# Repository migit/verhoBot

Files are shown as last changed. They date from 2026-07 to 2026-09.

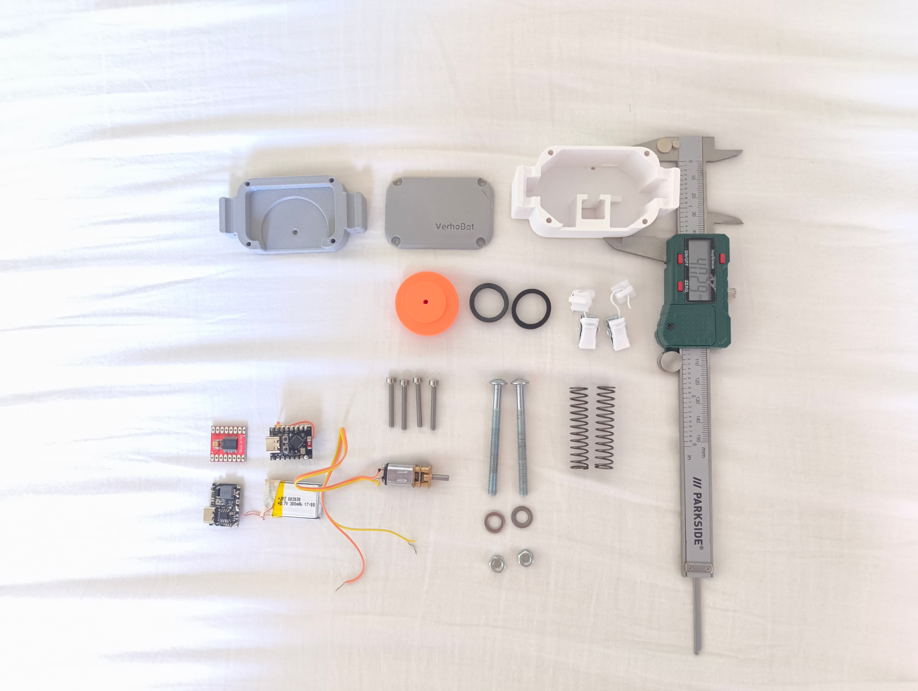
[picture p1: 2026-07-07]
VerhoBot/hardware/CAD/images/VerhoBot_parts.jpg

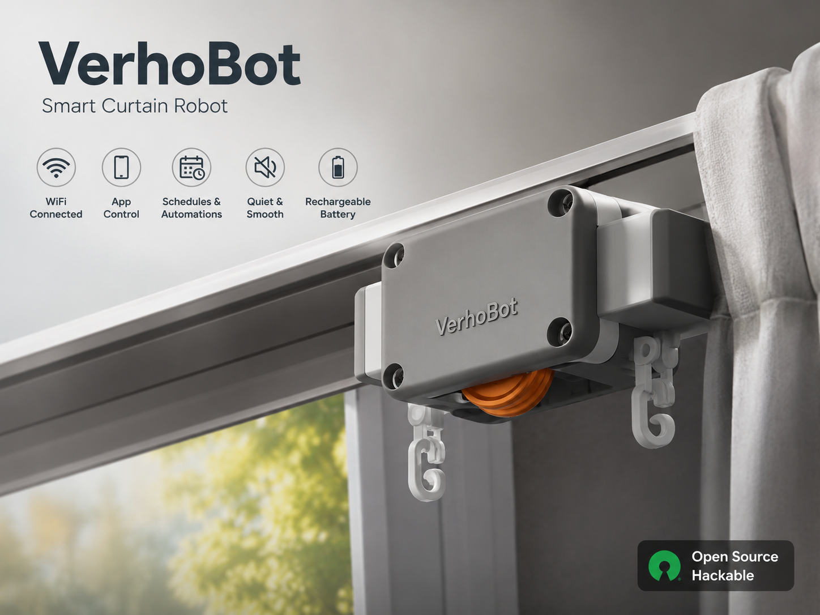
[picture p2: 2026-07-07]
VerhoBot/hardware/CAD/images/vb.png

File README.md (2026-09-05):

<!-- # VerhoBot
<img width="1536" height="1024" alt="verho_concept_design" src="https://github.com/user-attachments/assets/45290109-c627-40e5-b835-4a0c27403841" /> 
<img width="1536" height="1024" alt="verho_b" src="https://github.com/user-attachments/assets/ea8144e8-805f-48bb-890e-384471ef9897" /> -->

<!-- <img width="1535" height="1024" alt="verho_banner" src="https://github.com/user-attachments/assets/6782ed62-eeb0-4958-a5c3-7888029129f1" /> 

<img width="1535" height="1024" alt="verho_banner_white" src="https://github.com/user-attachments/assets/3a6c4d62-edfc-40f7-b2f0-12bc582d1462" /> -->

<picture>
  <source media="(prefers-color-scheme: dark)" srcset="https://github.com/user-attachments/assets/aba6153e-b872-4d4a-9a58-02b24fb0d8ed">
  <source media="(prefers-color-scheme: light)" srcset="https://github.com/user-attachments/assets/56020f1e-bfad-4f00-b733-0ede581f7c40">
  verho_banner
</picture>

<div align="center">

### The Tiny Bot That Opens and Closes Your Curtains for You

*Sleep in darkness. Wake up with sunlight.*

[]()
[]()
[]()
[]()


[]()


</div>

---

## Overview

VerhoBot is an open-source smart curtain robot designed to automate existing curtain rails using affordable, widely available hardware and fully customizable software.

The project was born from a simple observation: many people use blackout curtains to improve sleep quality, but those same curtains prevent natural sunlight from entering the room when it is time to wake up. This challenge is particularly noticeable during the Finnish summer, when long daylight hours and bright nights can disrupt normal sleep patterns.

VerhoBot addresses this problem by providing a compact robotic platform capable of opening and closing curtains automatically according to schedules, user commands, or future smart-home automations.

Unlike many commercial curtain robots, VerhoBot is designed from the beginning as an open-source project. Every aspect of the system including hardware design, firmware, mechanical components, and future software integrations is intended to be accessible, modifiable, and extensible by makers, students, engineers, and hobbyists.

**VerhoBot** solves both problems.

VerhoBot is a compact curtain-moving robot designed to automatically close your curtains when you need darkness and open them again when it is time to wake up. The goal is simple: improve sleep quality while letting natural sunlight become part of your morning routine.

Built around the ESP32 platform, VerhoBot aims to be affordable, repairable, open-source, and easy to integrate into modern smart homes.

---

## Features

### Current Goals

- Automatic curtain opening and closing
- Compact rail-mounted design
- Battery-powered operation
- ESP32-based controller
- Quiet operation
- USB-C charging
- Low-power sleep modes
- Open-source hardware and software

### Planned Features

- Scheduled curtain control 
- Sunrise and sunset automation
- Home Assistant integration
- Mobile configuration
- OTA firmware updates
- Battery monitoring
- Manual override controls
- Position calibration
- Smart alarm mode

---

## Why?

Finland's summer is famous for its bright nights.

While blackout curtains help create a dark sleeping environment, they also block the morning sunlight that helps regulate the body's natural wake-up cycle.

VerhoBot combines the best of both worlds:

- Darkness when you need sleep
- Sunlight when it is time to wake up

No alarms.
No bright phone screens.
Just natural light at the right moment.
The long-term vision of VerhoBot is to create a flexible, affordable, and fully open curtain automation platform that can evolve through community contributions.
Rather than competing with commercial smarthome products, VerhoBot aims to give users complete ownership of their hardware, software, and data while remaining accessible to makers of all skill levels.

## Comunity Goals

The project aims to provide a practical open-source platform for learning:

Embedded systems
ESP32 development
Mechanical design
Battery-powered electronics
IoT communication
Smart-home integration
Product development

Whether you are building your first ESP32 project or developing advanced automation systems, VerhoBot should provide a foundation that is easy to understand, modify, and improve.

---

## Hardware

###  Electronics

| Component | Purpose |
|---|---|
| ESP32-C3 supermini | Main controller |
| N20 Geared DC Motor (100 RPM 6V works best without loosing good torque and speed) | Curtain movement |
| Motor Driver (TB6612FNG is chosen for best effeciency and size form factor) | Motor control |
| Li-Ion Battery (3.7v 300mAh is chosen) | Portable power |
| USB-C Charger | Charging interface |
| Position Sensors (note yet decide, but position calibration is now done in the firmware for now : const uint32_t CURTAIN_TRAVEL_TIME = 4000;)| Open/close detection |

### schematic

<picture>
  <source media="(prefers-color-scheme: dark)" srcset="https://github.com/user-attachments/assets/5fd002bf-6933-44c8-951e-679d403ac9f6">
  <source media="(prefers-color-scheme: light)" srcset="https://github.com/user-attachments/assets/78fb31f9-d5d8-4c3f-95c0-13649d746854">
  verho_banner
</picture>

### PCB design
-PCB design is active now, I will release the first draft, so that the community can comment on it before it is has been manufactured (Help is wanted here)

###  Mechanical Design

vbot1

- Compact form factor
- Rail-mounted operation
- Existing curtain compatibility
- 3D-printable enclosure built arround the designed PCB board
- Modular internal architecture

<div align="center">
  <a href="https://www.youtube.com/watch?v=YXQe8-dixHU">
    Watch the video
  </a>
</div>

<div align="center">
  <a href="https://youtu.be/6-GEg8fdRDQ?si=6PpPOxxIadroxERF">
    Watch the video
  </a>
</div>

### Parts

VerhoBot_parts

[Join the thingsverse community here](https://www.thingiverse.com/thing:7370927)

---

## Software Roadmap

### Phase 1

- Basic motor control [Done]
- Position calibration [Done]
- Manual open/close control [Done]

### Phase 2

- Scheduling system [Done]
- Battery monitoring [Done]
- Configuration interface [Done] 

### Phase 3

- OTA updates [Done]
- Web-based firmware flasher (Done,)
- Home Assistant integration [Pending...for Version 2]
- Smart automation features [Pending... for Version 2]

### NOTE: All software, firware and hardware works of this project is complete and in stable version but verho bot is still evolving as V2 as next generation VerhoBot, meanning This repo (V1) will continue to be mainatined and evolve without affecting the OSHWA certification standard and what it promised to deliver. 

---

## operation

<!-- <img width="1264" height="833" alt="op_mode" src="https://github.com/user-attachments/assets/f6f8d905-06a9-4c95-84db-494406e7b41f" /> -->
VerhoBot - visual selection

## How it suppose to behave:
- First boot -> AP VerhoBot-Setup -> dashboard at 192.168.4.1 -> click ⚙ to enter WiFi & schedule -> save -> reboot.
- Normal operation -> connects to home WiFi -> syncs time -> sleeps.
- Scheduled wake -> moves curtain -> starts web server -> stays awake 60 s -> sleeps.
- Button wake -> toggles curtain -> starts web server -> stays awake 60 s -> sleeps.
- During the 60‑second awake window, you can open your browser, go to the device’s IP (shown in Serial), and see the full dashboard, control the curtain, and check telemetry.
- After 60 s of inactivity, it goes back to deep sleep.

## Quick Troubleshooting:

- It restarts automatically after saving, and should join your home WiFi. The VerhoBot-Setup network will disappear (expected - that's the sign it's now trying your real WiFi).
- Find it on your network. It'll get an IP from your router. Easiest way: check your router's connected-devices list for "verhobot" or similar, or use a phone WiFi scanner app / your router admin page. There's no verhobot.local mDNS support yet, so this is the one manual step for now.
- Open the dashboard at that IP. You should see the schedule card showing your configured open/close times and a live countdown to the next action.
If it doesn't show up on your network within a minute or two, it likely couldn't connect (wrong password, wrong network, etc.) - with the fix from earlier, it'll fall back to broadcasting VerhoBot-Setup again so you can fix the credentials. Reconnect to that and try /setup again.
- Calibrate the position once it's mounted on the actual curtain rail - run it fully open and fully closed once, then use the "set as fully open / fully closed" buttons on the dashboard so the tracked position matches reality (it's timing-based, not sensor-based, so it can drift).
- Mount it and let it run unattended - check back around your first scheduled open/close time to confirm it moves as expected, then it should just run on its own, waking briefly at each scheduled event and sleeping the rest of the time.

- If it connects fine and everything looks right, you're basically done - just keep an eye on battery level on the dashboard for the first few days to get a sense of how long it lasts between charges.

## Project Status

```text

v_0.1.0-beta1.2  -> Firmware complete
v_0.1.0-beta1.1  -> Testing and tuning
v_0.1.0-beta1  ->   Manual open/close control
v1.0  -> Stable release
v1.1  -> Stable with Improved dashboard
V1.2  -> OTA feature added
V1.2.1 -> Fixed a boot button deep sleep wake to GPIO1 as esp32-c3 does not support this
```

Active patching is ongoing but stable phase.

## Lesson Learned 

- So far verhoBot is being tested for over two weeks, firmware bug is being fixed so plugging and unplugging the USB C was a headache, so impliment OTA at the early stage saved me time.
- Control & config dashboard is being improved scheduling,OTA update, home wifi connect and curtain calibration (time based) are working flowlessly these are small features so working on them separately was a good idea even if they seem small and manageable.
- On the hardware side wakr up GPIO has been added. Before, it was suppose to work with boot button press which the esp32-c super mini board does not support
- The deep sleep has saved lots of battery life but the LED (I call it the terminator eye) glows in the dark was cool indicating the bot is on but still consumes battery life, in the future desoldering it from the board will defenetly save some more battery life.
- The Li-Po battery I am using is 300mAh, still the bot runs for 6 days straight...(I will update this when I finish experimenting on it!).I leaned battery size (physical size) matters and as the battery gets bigger the form factor of the bot case changes I should have considered this before I designed the case but hey, now harm!

--- 

## Design Principles

VerhoBot follows a few simple rules:

- Open-source first
- Repairable hardware
- Affordable components
- Low power consumption
- Easy to build
- Easy to modify
- No vendor lock-in (you own everything)

---

## Future versions may incorporate:

- Position sensing
- Motor current monitoring
- Automatic obstacle detection
- Endstop detection
- Environmental sensors
- Advanced power management

---

## Demo

#Dashboard preview:

https://github.com/user-attachments/assets/f727beac-c3cd-45c5-90aa-1bad3a5c13f2

## Contributing

Contributions, ideas, testing feedback, and hardware improvements are welcome.
As the project evolves, documentation, CAD files, schematics, and firmware source code will be published in this repository.

---

## License

Distributed under the MIT License.
See `LICENSE` for more information.

VerhoBot has been officially certified as Open Source Hardware by the Open Source Hardware Association (OSHWA).

- **Certification UID:** FI000004
- **Certification Date:** 2026
- **Status:** OSHWA Certified Open Source Hardware

This project complies with the Open Source Hardware Definition and all design files are publicly available.
For more information about Open Source Hardware certification, visit the Open Source Hardware Association (OSHWA).

[OSHWA Certified Open Source Hardware FI000004](https://certification.oshwa.org/fi000004.html)

---

<div align="center">

### VerhoBot

*Built for the Finnish summer. Makers for Makers*

</div>

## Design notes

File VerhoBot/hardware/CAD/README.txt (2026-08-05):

# VerhoBot

**Designed by MikeMakesStuffs on Thingiverse**
**Thingiverse:** https://www.thingiverse.com/thing:7370927

---

# Summary

**VerhoBot** is an open-source smart curtain robot designed to automate existing curtain rails using affordable, widely available hardware.

Built around the **ESP32-C3 Super Mini** and an **N20 geared motor**, VerhoBot is easy to build, easy to modify, and completely open source. Whether you need a simple curtain timer or a fully featured smart-home device, VerhoBot provides a flexible platform for makers, engineers, and DIY enthusiasts.

---

# Why VerhoBot?

Many people use blackout curtains to improve sleep quality, but waking up naturally with sunlight is just as important.

VerhoBot automatically opens or closes your curtains:

- On a schedule
- Through a web interface
- Via future smart-home integrations

The project was inspired by Finnish summers, where bright nights and early morning sunlight can make maintaining a healthy sleep schedule difficult.

---

# Features

- ESP32-C3 Super Mini based
- Battery powered (LiPo)
- USB-C charging
- N20 geared motor
- TB6612FNG motor driver
- Built-in Wi-Fi web control dashboard
- Configure and calibrate directly from the browser
- Fully 3D printable enclosure *(stable release with only minor refinements remaining)*
- Open-source firmware
- Modular hardware design
- Designed specifically for curtain rails
- Lightweight and compact

---

# Firmware

The firmware is continuously updated.

Latest releases are available here:

**Firmware Flasher:**

https://myworks.gt.tc/verhobot/

---

# Hardware

## Current Version (V1)

- ESP32-C3 Super Mini
- N20 DC Geared Motor
  - Recommended: **100 RPM 6V**
  - Good balance between speed and torque
- TB6612FNG Motor Driver
- TP4056 Charging Module
- 3.7V LiPo Battery
  - Recommended capacity: **300 mAh**
- MT3608 Boost Converter *(optional if the TP4056 includes a built-in boost converter)*
- Custom 3D printed enclosure and mechanical components

---

# Open Source

VerhoBot is intended to be a community-driven project.

Future community extensions may include:

- Home Assistant integration
- MQTT support
- Matter compatibility
- Zigbee connectivity
- Position tracking
- Automatic calibration
- Obstacle detection
- Battery optimization
- Solar charging
- Mobile applications

Contributions, remixes, improvements, and pull requests are always welcome.

---

# Source Code & Documentation

## GitHub Repository

https://github.com/migit/verhoBot

The repository contains:

- Firmware
- Firmware Flasher
- Electronics documentation
- Schematics
- 3D models
- Build instructions
- Future development roadmap

Firmware is also hosted here:

https://myworks.gt.tc/verhobot/

---

# Philosophy

> **Build it. Improve it. Share it.**

VerhoBot is more than a curtain robot.

It is an open platform for learning:

- Embedded systems
- Mechanical design
- Battery-powered electronics
- Smart-home automation

If you build one, remix it, improve it, or adapt it for your own project, please share your version with the community.

---

# Current Project Status

## Firmware is now in a stable version!

### announcement 

Development on the hardware side has slowed down for the summer.
The current **VerhoBot V1.0** hardware is fully functional, while software development will continue to expand its capabilities.

Now it's your turn:
 
- Hack it
- Improve it
- Customize it
- Make it even better
---

# Thank You

Thank you all so much for your support!

---

# Videos

## Full Build Video

https://www.youtube.com/watch?v=6-GEg8fdRDQ

## Tinkering Demo

https://www.youtube.com/watch?v=YXQe8-dixHU

---

# Sleep in darkness. Wake up with sunlight.

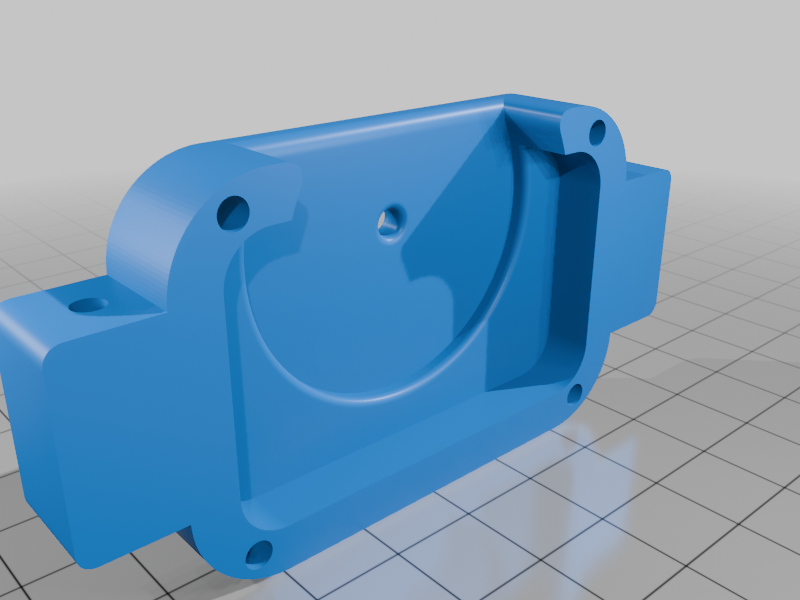
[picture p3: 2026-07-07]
VerhoBot/hardware/CAD/images/VerhoBot_-_front.png

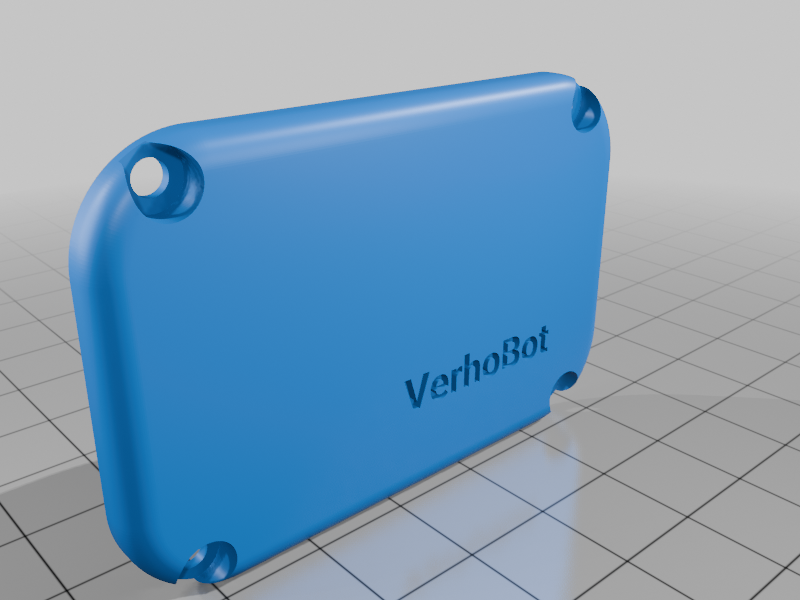
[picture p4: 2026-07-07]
VerhoBot/hardware/CAD/images/cover_face_-_Part_1.png

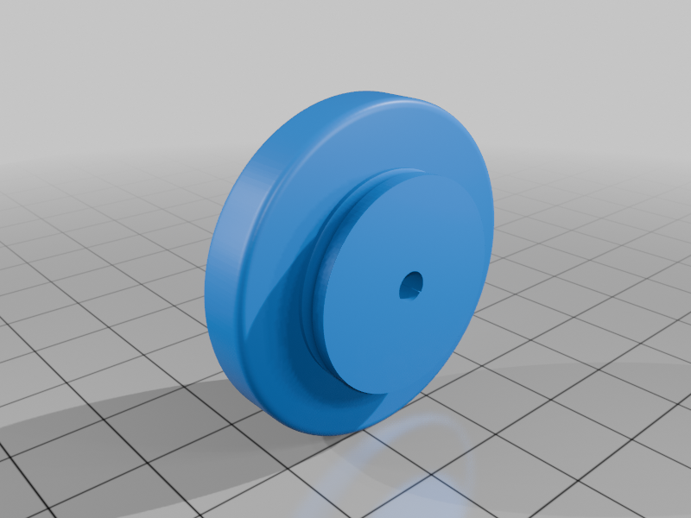
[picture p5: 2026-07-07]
VerhoBot/hardware/CAD/images/VerhoBot_-_Part_1_1.png

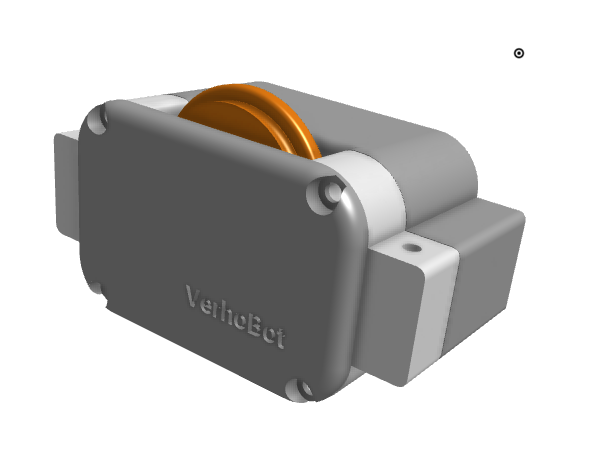
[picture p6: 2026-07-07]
VerhoBot/hardware/CAD/images/verho.png

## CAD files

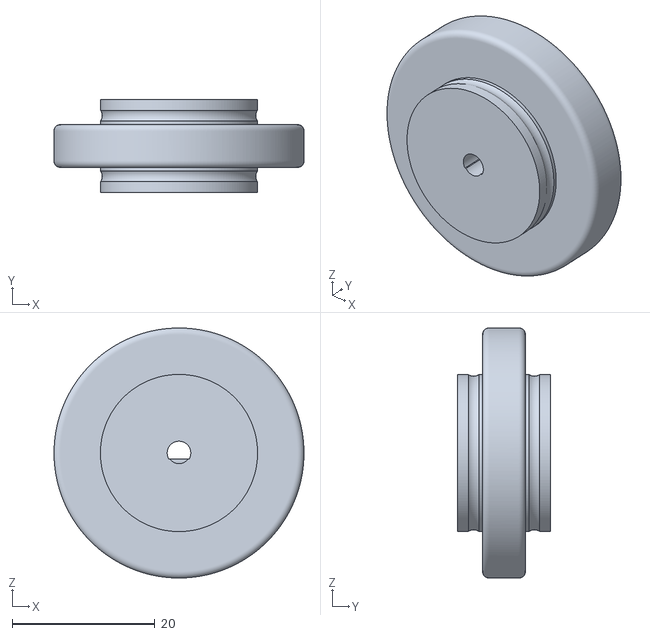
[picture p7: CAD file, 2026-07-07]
VerhoBot/hardware/CAD/files/VerhoBot_-_Part_1_1.stl
35.0 x 13.0 x 35.0

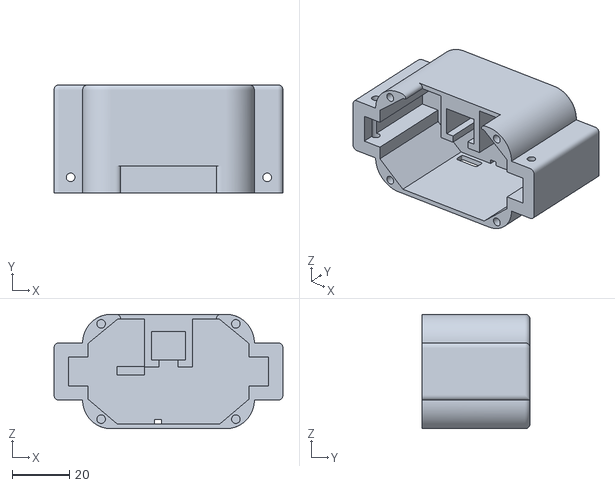
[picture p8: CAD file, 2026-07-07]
VerhoBot/hardware/CAD/files/VerhoBot_-_back.stl
80.0 x 37.8 x 40.0

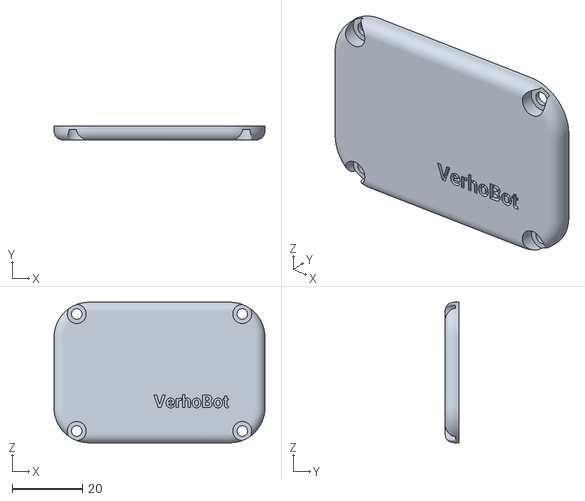
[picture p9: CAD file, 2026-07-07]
VerhoBot/hardware/CAD/files/cover_face_-_Part_1.stl
60.0 x 4.00 x 40.0

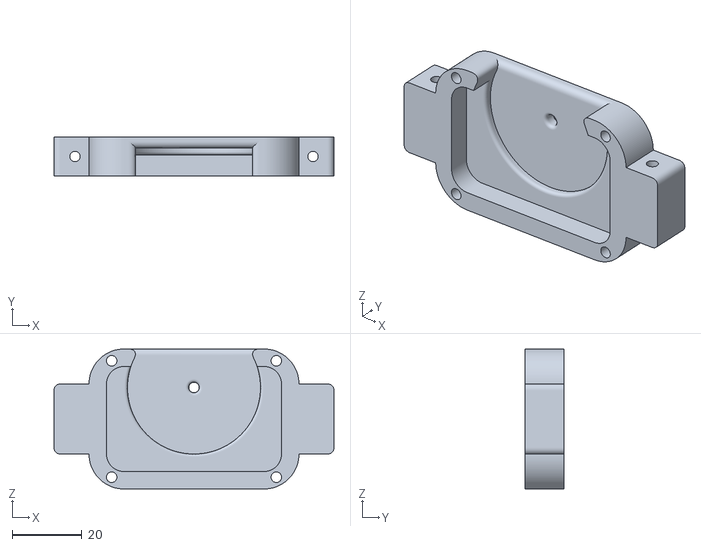
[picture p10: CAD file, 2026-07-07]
VerhoBot/hardware/CAD/files/VerhoBot_-_front.stl
80.0 x 11.0 x 40.0

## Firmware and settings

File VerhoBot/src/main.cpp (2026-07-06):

#include <Arduino.h>
#include <WiFi.h>
#include <WebServer.h>
#include <Preferences.h>
#include <time.h>
#include <esp_sleep.h>
#include <ArduinoJson.h>
#include <Update.h>

#include "pins.h"

// ============================================================
//  RTC memory – survives deep sleep
// ============================================================
RTC_DATA_ATTR float rtcCurtainPos = 0.0f;
RTC_DATA_ATTR uint32_t rtcBootCount = 0;

// ============================================================
//  Preferences (non‑volatile storage)
// ============================================================
Preferences prefs;

// ============================================================
//  Global state
// ============================================================
enum CurtainState { IDLE, OPENING, CLOSING };
CurtainState state = IDLE;

uint32_t moveStart    = 0;
uint32_t moveDuration = 0;
float    curtainPos   = 0.0f;   // 0.0 = fully open, 1.0 = fully closed

// Configuration loaded from Preferences
String wifiSSID = "";
String wifiPass = "";
int    openHour = 7;
int    openMin  = 0;
int    closeHour = 22;
int    closeMin  = 0;
String tzString  = TIMEZONE_STRING;
String otaToken  = ""; // empty = OTA disabled until set in /setup
bool   configured = false;
bool   otaInProgress = false; // guards against deep-sleeping mid-flash-write
bool   otaAuthFailed = false; // set when the passcode check fails; checked before reboot

// Web server
WebServer server(80);

// Awake timeout (STA mode only)
uint32_t awakeStart = 0;
const uint32_t AWAKE_TIMEOUT = 60000;  // 60 seconds after motor stops

// ============================================================
//  Motor control (non‑blocking, PWM soft start / soft stop)
// ============================================================
// PWMA is driven via LEDC instead of digitalWrite so we can ramp the duty
// cycle. Direction pins (AIN1/AIN2) stay as plain digital outputs.

void motorSetDuty(uint8_t duty) {
#if ESP_ARDUINO_VERSION_MAJOR >= 3
    ledcWrite(PWMA, duty);           // core 3.x: pin-addressed LEDC
#else
    ledcWrite(PWM_CHANNEL, duty);    // core <3.0: channel-addressed LEDC
#endif
}

void motorOpen() {
    digitalWrite(AIN1, HIGH);
    digitalWrite(AIN2, LOW);
    motorSetDuty(0); // ramp handled by updateMotor()
}

void motorClose() {
    digitalWrite(AIN1, LOW);
    digitalWrite(AIN2, HIGH);
    motorSetDuty(0); // ramp handled by updateMotor()
}

void motorStop() {
    digitalWrite(AIN1, LOW);
    digitalWrite(AIN2, LOW);
    motorSetDuty(0);
}

void startOpen(uint32_t ms) {
    if (curtainPos <= 0.01f) return;
    motorOpen();
    state = OPENING;
    moveStart = millis();
    moveDuration = ms;
    awakeStart = millis(); // keep awake while moving
}

void startClose(uint32_t ms) {
    if (curtainPos >= 0.99f) return;
    motorClose();
    state = CLOSING;
    moveStart = millis();
    moveDuration = ms;
    awakeStart = millis(); // keep awake while moving
}

void stopMotor() {
    if (state != IDLE) {
        float fraction = (float)(millis() - moveStart) / (float)moveDuration;
        fraction = constrain(fraction, 0.0f, 1.0f);
        if (state == OPENING) curtainPos = max(curtainPos - fraction, 0.0f);
        if (state == CLOSING) curtainPos = min(curtainPos + fraction, 1.0f);
    }
    motorStop();
    state = IDLE;
    awakeStart = millis(); // start the 60‑second countdown
}

// Linearly ramps duty from `from` to `to` over [0, rampMs] given `elapsed`.
static uint8_t rampDuty(uint32_t elapsed, uint32_t rampMs, uint8_t from, uint8_t to) {
    if (rampMs == 0 || elapsed >= rampMs) return to;
    float t = (float)elapsed / (float)rampMs;
    return (uint8_t)(from + t * ((float)to - (float)from));
}

void updateMotor() {
    if (state == IDLE) return;

    uint32_t elapsed = millis() - moveStart;

    if (elapsed >= moveDuration || elapsed >= MAX_RUN_TIME) {
        stopMotor();
        return;
    }

    uint32_t remaining = moveDuration - elapsed;

    uint8_t duty;
    if (elapsed < MOTOR_RAMP_UP_MS) {
        // Soft start: 0 -> full speed
        duty = rampDuty(elapsed, MOTOR_RAMP_UP_MS, 0, PWM_MAX_DUTY);
    } else if (remaining < MOTOR_RAMP_DOWN_MS) {
        // Soft stop: full speed -> min duty (stopMotor() cuts the rest cleanly)
        uint32_t decelElapsed = MOTOR_RAMP_DOWN_MS - remaining;
        duty = rampDuty(decelElapsed, MOTOR_RAMP_DOWN_MS, PWM_MAX_DUTY, MOTOR_MIN_DUTY);
    } else {
        duty = PWM_MAX_DUTY;
    }

    motorSetDuty(duty);
}

// Drive toward an absolute position (0.0 = fully open, 1.0 = fully closed),
// scaling the move duration to the remaining distance so the dashboard's
// drag-to-set slider lands close to where the user dropped it.
void gotoPosition(float targetPos) {
    targetPos = constrain(targetPos, 0.0f, 1.0f);
    float diff = targetPos - curtainPos;
    if (fabs(diff) < 0.01f) return; // already there
    uint32_t ms = (uint32_t)(fabs(diff) * CURTAIN_TRAVEL_TIME);
    if (ms < 80) return; // too small a move to bother with
    if (diff > 0) startClose(ms);
    else          startOpen(ms);
}

// ============================================================
//  Battery monitoring
// ============================================================
float readBatteryVoltage() {
    uint32_t sum = 0;
    for (uint8_t i = 0; i < ADC_SAMPLES; i++) sum += analogRead(BATTERY_ADC);
    float adcVoltage = ((float)(sum / ADC_SAMPLES) / 4095.0f) * 3.3f;
    return adcVoltage * BATTERY_CAL;
}

// ============================================================
//  Preferences (save / load / clear)
// ============================================================
void saveConfig(String ssid, String pass, int oh, int om, int ch, int cm, String tz, String ota) {
    prefs.begin("verhobot", false);
    prefs.putString("ssid", ssid);
    prefs.putString("pass", pass);
    prefs.putInt("openH", oh);
    prefs.putInt("openM", om);
    prefs.putInt("closeH", ch);
    prefs.putInt("closeM", cm);
    prefs.putString("tz", tz);
    prefs.putString("ota", ota);
    prefs.putBool("configured", true);
    prefs.end();
}

void loadConfig() {
    prefs.begin("verhobot", true);
    wifiSSID   = prefs.getString("ssid", "");
    wifiPass   = prefs.getString("pass", "");
    openHour   = prefs.getInt("openH", 7);
    openMin    = prefs.getInt("openM", 0);
    closeHour  = prefs.getInt("closeH", 22);
    closeMin   = prefs.getInt("closeM", 0);
    tzString   = prefs.getString("tz", TIMEZONE_STRING);
    otaToken   = prefs.getString("ota", "");
    configured = prefs.getBool("configured", false);
    prefs.end();
}

void clearConfig() {
    prefs.begin("verhobot", false);
    prefs.clear();
    prefs.end();
    configured = false;
}

// ============================================================
//  Time / NTP sync (with timeout)
// ============================================================
bool syncTime() {
    if (WiFi.status() != WL_CONNECTED) return false;
    // Use a POSIX TZ string (configurable, see /setup) instead of raw UTC
    // offsets so DST is handled automatically. Previously this called
    // configTime(0, 0, ...), which left the RTC in UTC and made scheduled
    // open/close times silently off by 2-3 hours in Finland.
    configTzTime(tzString.c_str(), "pool.ntp.org", "time.google.com");
    time_t now = time(nullptr);
    int attempts = 0;
    while (now < 8 * 3600 * 2 && attempts < 30) {
        delay(250);
        now = time(nullptr);
        attempts++;
    }
    return (now > 8 * 3600);
}

String getTimeString() {
    time_t now = time(nullptr);
    struct tm *info = localtime(&now);
    char buf[30];
    strftime(buf, sizeof(buf), "%Y-%m-%d %H:%M:%S", info);
    return String(buf);
}

// ============================================================
//  Deep sleep preparation
// ============================================================
struct NextEvent {
    bool     isOpenEvent; // true = the pending action is OPEN, false = CLOSE
    int      hour;
    int      minute;
    uint64_t secondsUntil;
};

NextEvent computeNextEvent() {
    NextEvent ev;
    time_t now = time(nullptr);
    struct tm *tm_now = localtime(&now);

    // BUGFIX: this used to pick the SAME edge the curtain just reached
    // (closed -> target closeHour again), which meant a device that fell
    // asleep closed would sleep straight through the next openHour and
    // only ever wake up at closeHour, 24h later. It must target the
    // *opposite* edge - the one that hasn't happened yet.
    if (curtainPos > 0.5f) {
        // currently closed -> next thing to do is OPEN
        ev.isOpenEvent = true;
        ev.hour = openHour;
        ev.minute = openMin;
    } else {
        // currently open -> next thing to do is CLOSE
        ev.isOpenEvent = false;
        ev.hour = closeHour;
        ev.minute = closeMin;
    }

    struct tm target = *tm_now;
    target.tm_hour = ev.hour;
    target.tm_min  = ev.minute;
    target.tm_sec  = 0;

    time_t targetTime = mktime(&target);
    if (targetTime <= now) targetTime += 86400;

    ev.secondsUntil = (uint64_t)(targetTime - now);
    return ev;
}

uint64_t calculateSleepSeconds() {
    return computeNextEvent().secondsUntil;
}

bool inFallbackAP = false; // true only when AP is up because STA failed post-config (see below)

void enterDeepSleep() {
    Serial.println("Entering deep sleep...");
    delay(100);

    rtcCurtainPos = curtainPos;

    motorStop();
    digitalWrite(STBY, LOW);

    WiFi.disconnect(true);
    WiFi.mode(WIFI_OFF);

    bool timeSynced = (time(nullptr) > 8 * 3600);
    uint64_t sleepSec;
    if (timeSynced) {
        sleepSec = computeNextEvent().secondsUntil;
    } else {
        // Clock isn't trustworthy (WiFi/NTP failed this cycle) - computing a
        // schedule-based sleep duration from an unsynced clock (effectively
        // Jan 1 1970) could sleep for a wildly wrong number of hours. Retry
        // again shortly instead of trusting it.
        sleepSec = UNSYNCED_RETRY_SEC;
        Serial.println("Clock not synced - using a short fixed retry interval instead of the schedule.");
    }

    esp_sleep_enable_timer_wakeup(sleepSec * 1000000ULL);

    // The ESP32-C3 is RISC-V and has no dedicated RTC GPIO mux, so it
    // doesn't support ext0/ext1 wakeup sources the way the original ESP32,
    // S2, and S3 do. It uses a separate GPIO wakeup API instead.
#if CONFIG_IDF_TARGET_ESP32 || CONFIG_IDF_TARGET_ESP32S2 || CONFIG_IDF_TARGET_ESP32S3
    esp_sleep_enable_ext1_wakeup(1ULL << WAKE_BUTTON_PIN, ESP_EXT1_WAKEUP_ANY_LOW);
#else
    esp_deep_sleep_enable_gpio_wakeup(1ULL << WAKE_BUTTON_PIN, ESP_GPIO_WAKEUP_GPIO_LOW);
#endif

    if (timeSynced) {
        Serial.printf("Sleeping for %llu seconds (schedule-based)\n", sleepSec);
    } else {
        Serial.printf("Sleeping for %llu seconds (retry, clock unsynced)\n", sleepSec);
    }
    Serial.flush();

    esp_deep_sleep_start();
}

// ============================================================
//  Web Server – Full Dashboard + Setup
// ============================================================

// ---------- DASHBOARD PAGE (with ghost animation) ----------
const char PAGE_DASHBOARD[] PROGMEM = R"rawhtml(
<!DOCTYPE html>
<html lang="en">
<head>
<meta charset="UTF-8">
<meta name="viewport" content="width=device-width, initial-scale=1">
<title>VerhoBot</title>
<style>
:root{
  --bg:#f5f4f0;--surface:#faf9f6;
  --ink:#1a1a1a;--ink2:#3a3a3a;
  --mute:#8a8a85;--rule:#c8c7c0;--rule2:#dddcd6;
  --green:#1a6b3a;--red:#8b1a1a;--amber:#8a5a00;
  --mono:'Courier New',Courier,'Lucida Console',monospace;
  --sans:-apple-system,BlinkMacSystemFont,'Segoe UI',Helvetica,Arial,sans-serif;
  /* Accent + sky follow the curtain state: warm dawn when open (daylight
     coming in), cool dusk when closed (night). Set by JS via body attrs. */
  --accent:#c2560c;--accent-dim:rgba(194,86,12,0.10);--accent-border:rgba(194,86,12,0.35);
  --sky-a:#f3e2c8;--sky-b:#f5f4f0;
}
body[data-phase="night"]{
  --accent:#38477a;--accent-dim:rgba(56,71,122,0.12);--accent-border:rgba(56,71,122,0.4);
  --sky-a:#20264a;--sky-b:#3a4472;
}
*,*::before,*::after{box-sizing:border-box;margin:0;padding:0;}
body{
  background:var(--bg);color:var(--ink);font-family:var(--sans);
  min-height:100vh;padding:1.5rem 1rem 3rem;
  background-image:
    linear-gradient(var(--rule2) 1px,transparent 1px),
    linear-gradient(90deg,var(--rule2) 1px,transparent 1px);
  background-size:24px 24px;
  transition:background .6s ease;
}
.wrap{max-width:480px;margin:0 auto;}

header{
  display:flex;justify-content:space-between;align-items:flex-start;
  border-bottom:2px solid var(--ink);padding-bottom:10px;margin-bottom:1rem;
  position:relative;
}
header::after{
  content:'';position:absolute;bottom:-2px;left:0;width:48px;height:2px;
  background:var(--accent);transition:background .6s ease;
}
.logo{
  font-family:var(--mono);font-size:1.5rem;letter-spacing:.1em;
  display:flex;align-items:baseline;gap:0;line-height:1;
}
.logo-verho{color:var(--ink);font-weight:normal;}
.logo-slash{color:var(--accent);margin:0 1px;transition:color .6s ease;}
.logo-bot{color:var(--accent);font-weight:bold;letter-spacing:.06em;transition:color .6s ease;}
.logo-sub{font-family:var(--mono);font-size:.5rem;letter-spacing:.2em;color:var(--mute);margin-top:5px;text-transform:uppercase;}
.hdr-right{text-align:right;}
.conn{font-family:var(--mono);font-size:.52rem;letter-spacing:.15em;text-transform:uppercase;
  display:flex;align-items:center;gap:5px;color:var(--green);justify-content:flex-end;}
.conn-dot{width:6px;height:6px;border-radius:50%;background:var(--green);animation:blink 2.5s steps(1) infinite;}
#conn-offline{color:var(--red);display:none;}
#conn-offline .conn-dot{background:var(--red);animation:none;}
@keyframes blink{0%,100%{opacity:1}50%{opacity:0}}
.mode-badge{font-family:var(--mono);font-size:.44rem;letter-spacing:.12em;color:var(--mute);margin-top:3px;text-transform:uppercase;}
.ip{font-family:var(--mono);font-size:.46rem;letter-spacing:.1em;color:var(--mute);margin-top:2px;}
.gear{display:inline-block;font-size:1.1rem;cursor:pointer;text-decoration:none;color:var(--mute);transition:transform 0.3s;margin-top:4px;}
.gear:hover{transform:rotate(60deg);color:var(--accent);}

.banner{
  font-family:var(--mono);font-size:.56rem;letter-spacing:.05em;
  padding:8px 10px;border:1px solid var(--amber);color:var(--amber);
  background:rgba(138,90,0,.06);margin-bottom:1rem;display:none;
  align-items:center;gap:8px;
}
.banner.show{display:flex;}
.banner.danger{border-color:var(--red);color:var(--red);background:rgba(139,26,26,.06);}
.banner-dot{width:6px;height:6px;flex:0 0 auto;border-radius:50%;background:currentColor;}

.section{
  font-family:var(--mono);font-size:.52rem;letter-spacing:.2em;text-transform:uppercase;
  color:var(--accent);margin-bottom:8px;display:flex;align-items:center;gap:8px;
  transition:color .6s ease;
}
.section::after{content:'';flex:1;height:1px;background:var(--rule);}

.curtain-block{border:1px solid var(--ink2);margin-bottom:1.25rem;}
.curtain-head{
  background:var(--ink);color:#f5f4f0;
  font-family:var(--mono);font-size:.58rem;letter-spacing:.18em;
  padding:5px 10px;display:flex;justify-content:space-between;
}
.curtain-head span:last-child{color:var(--accent);transition:color .6s ease;}
.curtain-vis{
  position:relative;height:96px;overflow:hidden;cursor:grab;
  background:linear-gradient(180deg,var(--sky-a),var(--sky-b));
  transition:background 1s ease;
  touch-action:none;
}
.curtain-vis:active{cursor:grabbing;}
.curtain-vis::before{content:'';position:absolute;top:0;left:0;right:0;height:3px;background:var(--ink);z-index:4;}
.drape{
  position:absolute;top:3px;left:0;height:calc(100% - 3px);
  background:var(--accent-dim);
  border-right:1.5px solid var(--accent-border);
  overflow:hidden;z-index:1;
  transition:background .6s ease,border-color .6s ease;
}
.drape::after{
  content:'';position:absolute;inset:0;
  background-image:repeating-linear-gradient(45deg,transparent,transparent 4px,rgba(0,0,0,.05) 4px,rgba(0,0,0,.05) 5px);
}
.drape-ghost{
  position:absolute;top:3px;left:0;height:calc(100% - 3px);
  background:transparent;border-right:2px dashed var(--accent-border);
  pointer-events:none;z-index:2;display:none;
}
.ring{position:absolute;top:-2px;width:7px;height:7px;border:1.5px solid var(--ink);border-radius:50%;background:var(--bg);transform:translateX(-50%);z-index:3;pointer-events:none;}
.handle{
  position:absolute;top:50%;width:16px;height:16px;border-radius:50%;
  background:#fff;border:2px solid var(--ink);transform:translate(-50%,-50%);
  z-index:5;box-shadow:0 1px 3px rgba(0,0,0,.3);
}
.curtain-foot{border-top:1px solid var(--rule);padding:6px 10px;display:flex;justify-content:space-between;align-items:center;}
.pos-scale{font-family:var(--mono);font-size:.46rem;letter-spacing:.05em;color:var(--mute);}
.pos-right{display:flex;align-items:center;gap:10px;}
.state-badge{
  font-family:var(--mono);font-size:.48rem;letter-spacing:.15em;text-transform:uppercase;
  padding:2px 7px;border:1px solid var(--ink2);color:var(--ink2);
}
.state-badge.opening,.state-badge.closing{border-color:var(--accent);color:var(--accent);}
.pos-pct{font-family:var(--mono);font-size:1rem;font-weight:700;color:var(--accent);transition:color .6s ease;}

.metrics{display:grid;grid-template-columns:1fr 1fr 1fr;border:1px solid var(--ink2);margin-bottom:1.25rem;}
.metric{padding:.75rem .9rem;border-right:1px solid var(--rule);}
.metric:last-child{border-right:none;}
.m-label{font-family:var(--mono);font-size:.46rem;letter-spacing:.18em;text-transform:uppercase;color:var(--mute);margin-bottom:5px;}
.m-val{font-family:var(--mono);font-size:.92rem;font-weight:700;line-height:1;}
.m-unit{font-family:var(--mono);font-size:.48rem;color:var(--mute);margin-left:1px;}
.bbar-row{margin-top:5px;display:flex;align-items:center;gap:5px;}
.bbar-track{flex:1;height:3px;background:var(--rule2);}
.bbar-fill{height:100%;background:var(--ink);transition:width .6s ease,background .3s ease;}

.sched-block{border:1px solid var(--ink2);margin-bottom:1.25rem;padding:.8rem .9rem;}
.sched-row{display:flex;justify-content:space-between;align-items:baseline;}
.sched-label{font-family:var(--mono);font-size:.46rem;letter-spacing:.16em;text-transform:uppercase;color:var(--mute);}
.sched-times{font-family:var(--mono);font-size:.6rem;color:var(--ink2);margin-top:4px;}
.sched-next{font-family:var(--mono);font-size:.78rem;font-weight:700;color:var(--accent);margin-top:2px;transition:color .6s ease;}
.sched-note{font-family:var(--mono);font-size:.46rem;color:var(--mute);margin-top:6px;}

.controls{display:grid;grid-template-columns:1fr 1fr 1fr;border:1px solid var(--ink2);margin-bottom:.6rem;}
.cmd{
  all:unset;cursor:pointer;
  font-family:var(--mono);font-size:.58rem;letter-spacing:.15em;text-transform:uppercase;
  text-align:center;color:var(--ink2);
  padding:.85rem .4rem;
  display:flex;flex-direction:column;align-items:center;gap:7px;
  border-right:1px solid var(--rule);
  transition:background .12s,color .12s,border-color .12s,opacity .2s;
  position:relative;
}
.cmd:last-child{border-right:none;}
.cmd:active{transform:scale(.98);}
.cmd[aria-disabled="true"]{opacity:.35;pointer-events:none;}
.cmd svg{width:22px;height:22px;stroke:var(--ink2);fill:none;stroke-width:1.5;stroke-linecap:round;stroke-linejoin:round;transition:stroke .12s;}
.cmd.open:hover,.cmd.close:hover{background:var(--accent);color:#fff;}
.cmd.open:hover svg,.cmd.close:hover svg{stroke:#fff;}
.cmd.stop:hover{background:var(--ink);color:#f5f4f0;}
.cmd.stop:hover svg{stroke:#f5f4f0;}

.calib-row{display:flex;justify-content:center;gap:1.5rem;margin-bottom:1.25rem;}
.calib-btn{
  all:unset;cursor:pointer;font-family:var(--mono);font-size:.46rem;letter-spacing:.1em;
  text-transform:uppercase;color:var(--mute);border-bottom:1px dotted var(--mute);
  padding-bottom:1px;
}
.calib-btn:hover{color:var(--accent);border-color:var(--accent);}

.log-block{border:1px solid var(--rule);margin-bottom:1.25rem;}
.log-head{font-family:var(--mono);font-size:.52rem;letter-spacing:.18em;text-transform:uppercase;color:var(--mute);padding:5px 10px;border-bottom:1px solid var(--rule);display:flex;justify-content:space-between;}
#log{padding:8px 10px;font-family:var(--mono);font-size:.58rem;color:var(--mute);line-height:2;min-height:80px;max-height:180px;overflow-y:auto;}
.lt{color:var(--rule);margin-right:8px;}
.ok{color:var(--green);}
.er{color:var(--red);}
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
void loop() {
    server.handleClient();
    updateMotor();

    // ---- AP mode: stay awake ----
    if (WiFi.getMode() == WIFI_AP) {
        // The never-configured setup AP (CASE 1) stays up indefinitely -
        // that's an out-of-box, actively-being-set-up state.
        // The fallback AP (saved credentials failed to connect) is bounded:
        // if nobody connects to fix it within AP_FALLBACK_TIMEOUT_MS, give
        // up and go back to sleep to retry the saved network later, rather
        // than burning battery broadcasting an AP with nobody around.
        if (inFallbackAP && millis() - awakeStart > AP_FALLBACK_TIMEOUT_MS) {
            Serial.println("No one connected to the fallback AP in time - sleeping to retry the saved network later.");
            enterDeepSleep();
        }
        return;
    }

    // ---- STA mode: sleep after 60s of idle ----
    if (otaInProgress) {
        // A firmware upload can easily take longer than AWAKE_TIMEOUT on a
        // slow network - never let it get cut off by a deep sleep mid-write.
        awakeStart = millis();
    } else if (state == IDLE) {
        if (millis() - awakeStart > AWAKE_TIMEOUT) {
            enterDeepSleep();
        }
    } else {
        // motor is moving – keep resetting the awake timer
        awakeStart = millis();
    }
}

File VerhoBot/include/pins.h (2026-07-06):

#ifndef PINS_H
#define PINS_H

// ---- Motor Driver (TB6612FNG) ----
#define AIN1    2
#define AIN2    3
#define PWMA    4
#define STBY    5

// ---- Battery Voltage Divider ----
#define BATTERY_ADC 0

// ---- Wake Button ----
// The ESP32-C3's onboard BOOT button is on GPIO9 - but the C3 only supports
// waking from DEEP sleep on GPIO0-5 (GPIO9 can wake from light sleep or
// trigger a normal reset, but not this). So the wake button can not be the
// module's built-in BOOT button; it has to be a separate button wired to
// one of GPIO0-5. GPIO1 is the only one of those not already used by the
// motor driver or battery sense, so that is what this needs to be wired to.
#define WAKE_BUTTON_PIN 1

// ---- Motor timing ----
#define CURTAIN_TRAVEL_TIME 4000   // ms for full travel (will be auto‑calibrated later)
#define MAX_RUN_TIME         8000  // safety cutoff
#define BATTERY_CAL          2.08f // voltage divider factor
#define ADC_SAMPLES          16

// ---- Motor PWM (soft start / soft stop) ----
#define PWM_FREQ              20000  // 20kHz, above audible range
#define PWM_RESOLUTION_BITS   8      // duty range 0-255
#define PWM_MAX_DUTY          ((1 << PWM_RESOLUTION_BITS) - 1)
#define PWM_CHANNEL           0      // only used on arduino-esp32 core < 3.0
#define MOTOR_RAMP_UP_MS      300    // time to reach full speed from stop
#define MOTOR_RAMP_DOWN_MS    300    // time to decelerate before a scheduled stop
#define MOTOR_MIN_DUTY        60     // duty floor while ramping (below this the motor may stall, not spin)

// ---- Timezone (POSIX TZ string) ----
// Default: Europe/Helsinki (EET/EEST with automatic DST).
// Change this if you build VerhoBot outside Finland.
// Reference table: https://github.com/nayarsystems/posix_tz_db
#define TIMEZONE_STRING "EET-2EEST,M3.5.0/3,M10.5.0/4"

// ---- WiFi connection / recovery timing ----
#define WIFI_CONNECT_TIMEOUT_MS   15000              // how long to try joining the saved network
#define AP_FALLBACK_TIMEOUT_MS    (5UL*60UL*1000UL)  // give up on fallback AP + go back to sleep after this
#define UNSYNCED_RETRY_SEC        (15UL*60UL)        // retry interval when NTP sync fails (clock can't be trusted for scheduling)

#endif

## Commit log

2026-06-16 Update ESP32 to ESP32-C3 in README
2026-06-22 Increase curtain travel time from 1000 to 4000 ms
    The bot travel time is increased for testing and calibration
2026-06-27 Add pins.h for motor driver and sensor definitions
    added wake up button use boot button (pin 0 for now)
2026-06-27 Update pins.h
    wake up button added, use BOOT button on ESP32‑C3 SuperMini, GPIO9 for now
2026-06-27 Update main.cpp
    patch missing dashboard html code
    [main.cpp]
2026-06-27 Document device operation and scheduled behavior
    Added operational behavior details for the device.
2026-07-02 Refactor motor control and time sync handling
    Refactor motor control to use PWM for soft start/stop and update time synchronization to handle DST automatically.
2026-07-02 Add motor PWM and timezone definitions in pins.h
    Timezone fix syncTime() now calls configTzTime(TIMEZONE_STRING, ...) with a POSIX TZ string ("EET-2EEST,M3.5.0/3,M10.5.0/4", defaulting to Europe/Helsinki with automatic DST) instead of configTime(0, 0, ...), which was silently running the whole schedule in UTC.
    [pins.h]
2026-07-04 Update fmt.Println message from 'Hello' to 'Goodbye'
    Better Dashboard, now virtual curtain is there in the UI so that you can drag it to position the bot
2026-07-04 Add PWM_CHANNEL definition for ESP32 core
2026-07-04 deep_sleep issues
    Fixed:
    If the saved credentials fail to connect right after a config save or a button press (both are "someone's right there" moments), it now reopens VerhoBot-Setup so you can fix it, instead of going dark.
    That fallback AP is time-boxed (5 min) - if nobody connects to fix it, the device goes back to sleep and retries the saved network at the next scheduled wake, so it doesn't just sit there burning battery unattended.
    I deliberately did not add this fallback to the scheduled/timer wake path - that one's unattended, and popping open an AP with nobody around to fix it would just drain the battery until someone notices. It keeps its current behavior of skipping the move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
    [main.cpp]
2026-07-04 WiFi connection recovery timing
    // ---- WiFi connection / recovery timing ----
    #define WIFI_CONNECT_TIMEOUT_MS 15000 // how long to try joining the saved network
    #define AP_FALLBACK_TIMEOUT_MS (5UL*60UL*1000UL) // give up on fallback AP + go back to sleep after this
    #define UNSYNCED_RETRY_SEC (15UL*60UL) // retry interval when NTP sync fails (clock can't be trusted for scheduling)
    [pins.h]
2026-07-06 WAKE_BUTTON_PIN was set to GPIO9 moved to GPIO1
    Fixed the real bug first: WAKE_BUTTON_PIN was set to GPIO9 (the module's onboard BOOT button), but the ESP32-C3 can only wake from deep sleep on GPIO0–5 to GPIO9 works for light sleep or a normal reset, but never actually wakes it from the state it is in right now. So the physical BOOT button has never been a working wake source since day one; only the timer wake was ever functional. Moved it to GPIO1, the one pin in that range not already claimed by the motor driver or battery sense. This means we now need a separate button wired to GPIO1 (with GND), not the onboard BOOT button
    [main.cpp]
2026-07-06 Modify wake button pin and add WiFi timing constants
    Updated the wake button definition and added WiFi connection timing constants.
2026-07-06 Update README with version 1.2.1 details
    Added version 1.2.1 with a fix for the boot button deep sleep wake issue on ESP32-C3.
2026-07-07 Add files via upload
    Hardware directory added, which contains first draft, PCB designs and previews

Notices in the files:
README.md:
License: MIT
